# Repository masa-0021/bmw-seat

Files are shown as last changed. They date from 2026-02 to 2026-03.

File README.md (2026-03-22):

# bmw-seat
## Introduction
Since my son is a huge fan of BMW, we created a small project:
* Buy a used passanger seat
* Create a small logic to allow him to enable e. g. seat heater, temperature indicator, and maybe some other equipment
* Screw the seat on a wooden plate and use it as furniture
This Readme shall guide you through the process in case you plan something similar.

### Credits
https://github.com/ironlungx/nvim-pio for providing the platformio plugin for neovim

### Part numbers
Before we rework the seat, let us summarize the different part numbers of the seat and its sub-components:
- Vehicle: BMW F10
- Airbag: 307130710-AD
- Head support: ks726381711
- Seat ECU: BMW 921646801
- Wiring harness: 9 259 205
- Connector: BMW 91676881


## Rework
As a first step, please use a professional service to remove the airbag from the seat. Please note that there might be legal requirements that have to be fulfilled. You should also disconnect the connector from the head support to the ECU below the seat to avoid any kind of emergency action.
In my case, I used a wooden plate (80mmx60mmx18mm) in combination with strips of wood to screw the seat to a wooden basis:
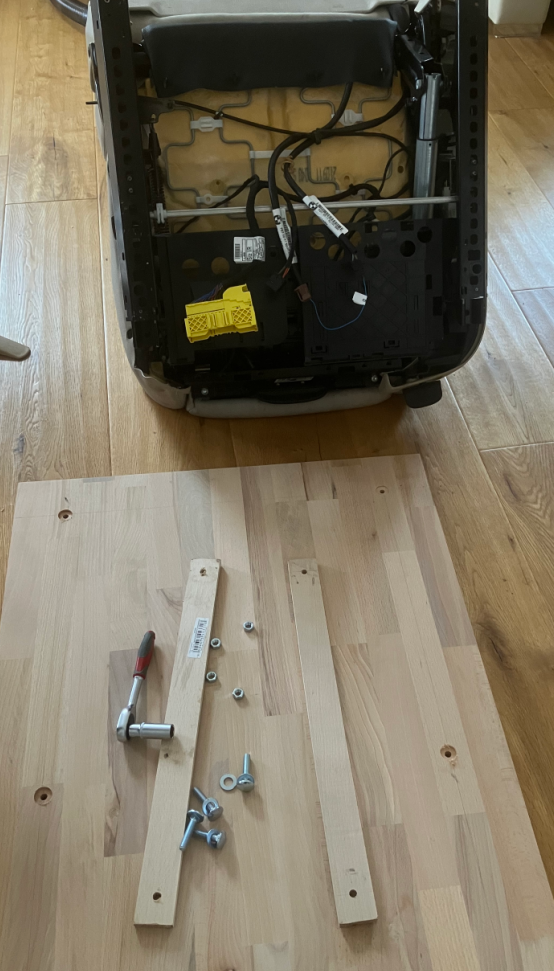
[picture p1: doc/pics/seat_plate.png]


## Electronics
### Seat heater
The seat uses an ECU to control the seat heater. Instead of using the ECU, I disconnected the wiring harness for the back rest and seating surface. Those wiring harnesses have three wires:
- Bround: GND
- Brown/Green: BAT (12V-14V)
- Light grey: Temperature information
According to some measurements, there are strong indications that the temperature pin is connected to GND via a 10kOhm NTC.
The planned implementation will be as follows: By enabling a heater switch, the heater is started. Due to safety concerns, both seat heaters are used in series. A timer of approx. 10mins starts after enabling the heat seater. Once the timer expires, the seat heater is switched off. Additionally, the 10kOhm NTC is monitored and at a temperature beyond 50degC (hysteresis 5degC), the heater is temporarily switched off.
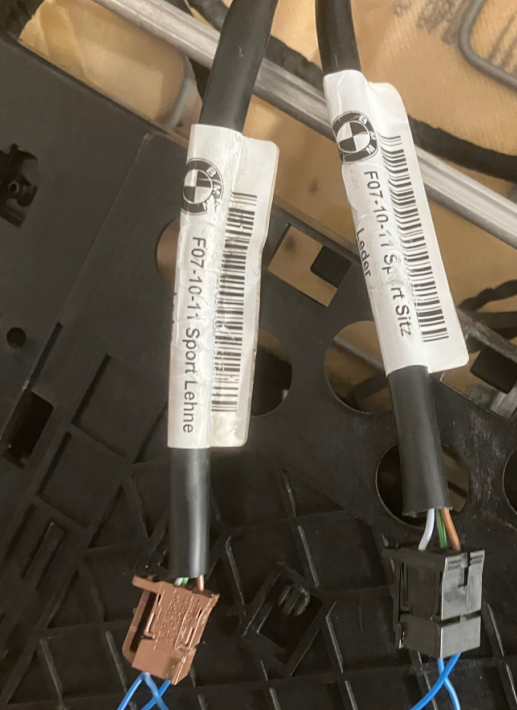
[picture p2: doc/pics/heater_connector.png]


### Fuse
I decided to protect the device with a 5A fuse. Consequently, due to the short wires, 0.5mm2 cable cross section is sufficient.

### Power supply
The system requires UBAT (12V-14V) and a 5V supply for the ATMEGA and the relay. In the first step, I used a passively cooled L7805 (1.5A). Unfortunately, cooling performance was not sufficient. Hence, I decided to use a DC/DC buck converter based on MP1584EN (max. 3A). The output voltage was depending on load and input voltage quite stable: 5.00V +/- 0.05V.

### Seat knobs
Once the main switch is enabled, the seat knobs to change the position of the seat can be used. You only need to connect GND and BAT (12V-14V) to the yellow main connector (brown and red/blue).
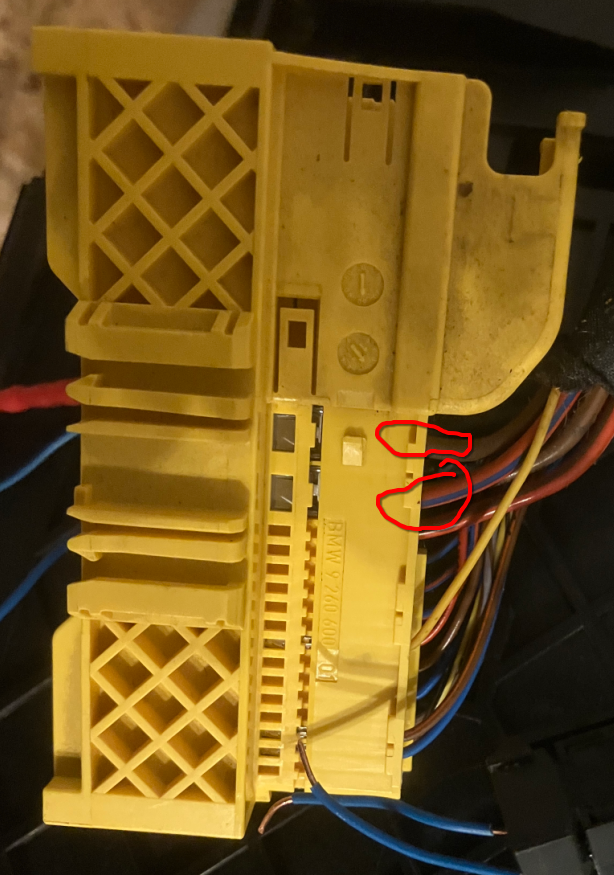
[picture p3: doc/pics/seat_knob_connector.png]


### Switches 
I used two key switches. The first one is a general switch for power supply, both for the seat as well as for the microcontroller ATMEGA328. The purpose of the 2nd switch is the start of the seat heater only.

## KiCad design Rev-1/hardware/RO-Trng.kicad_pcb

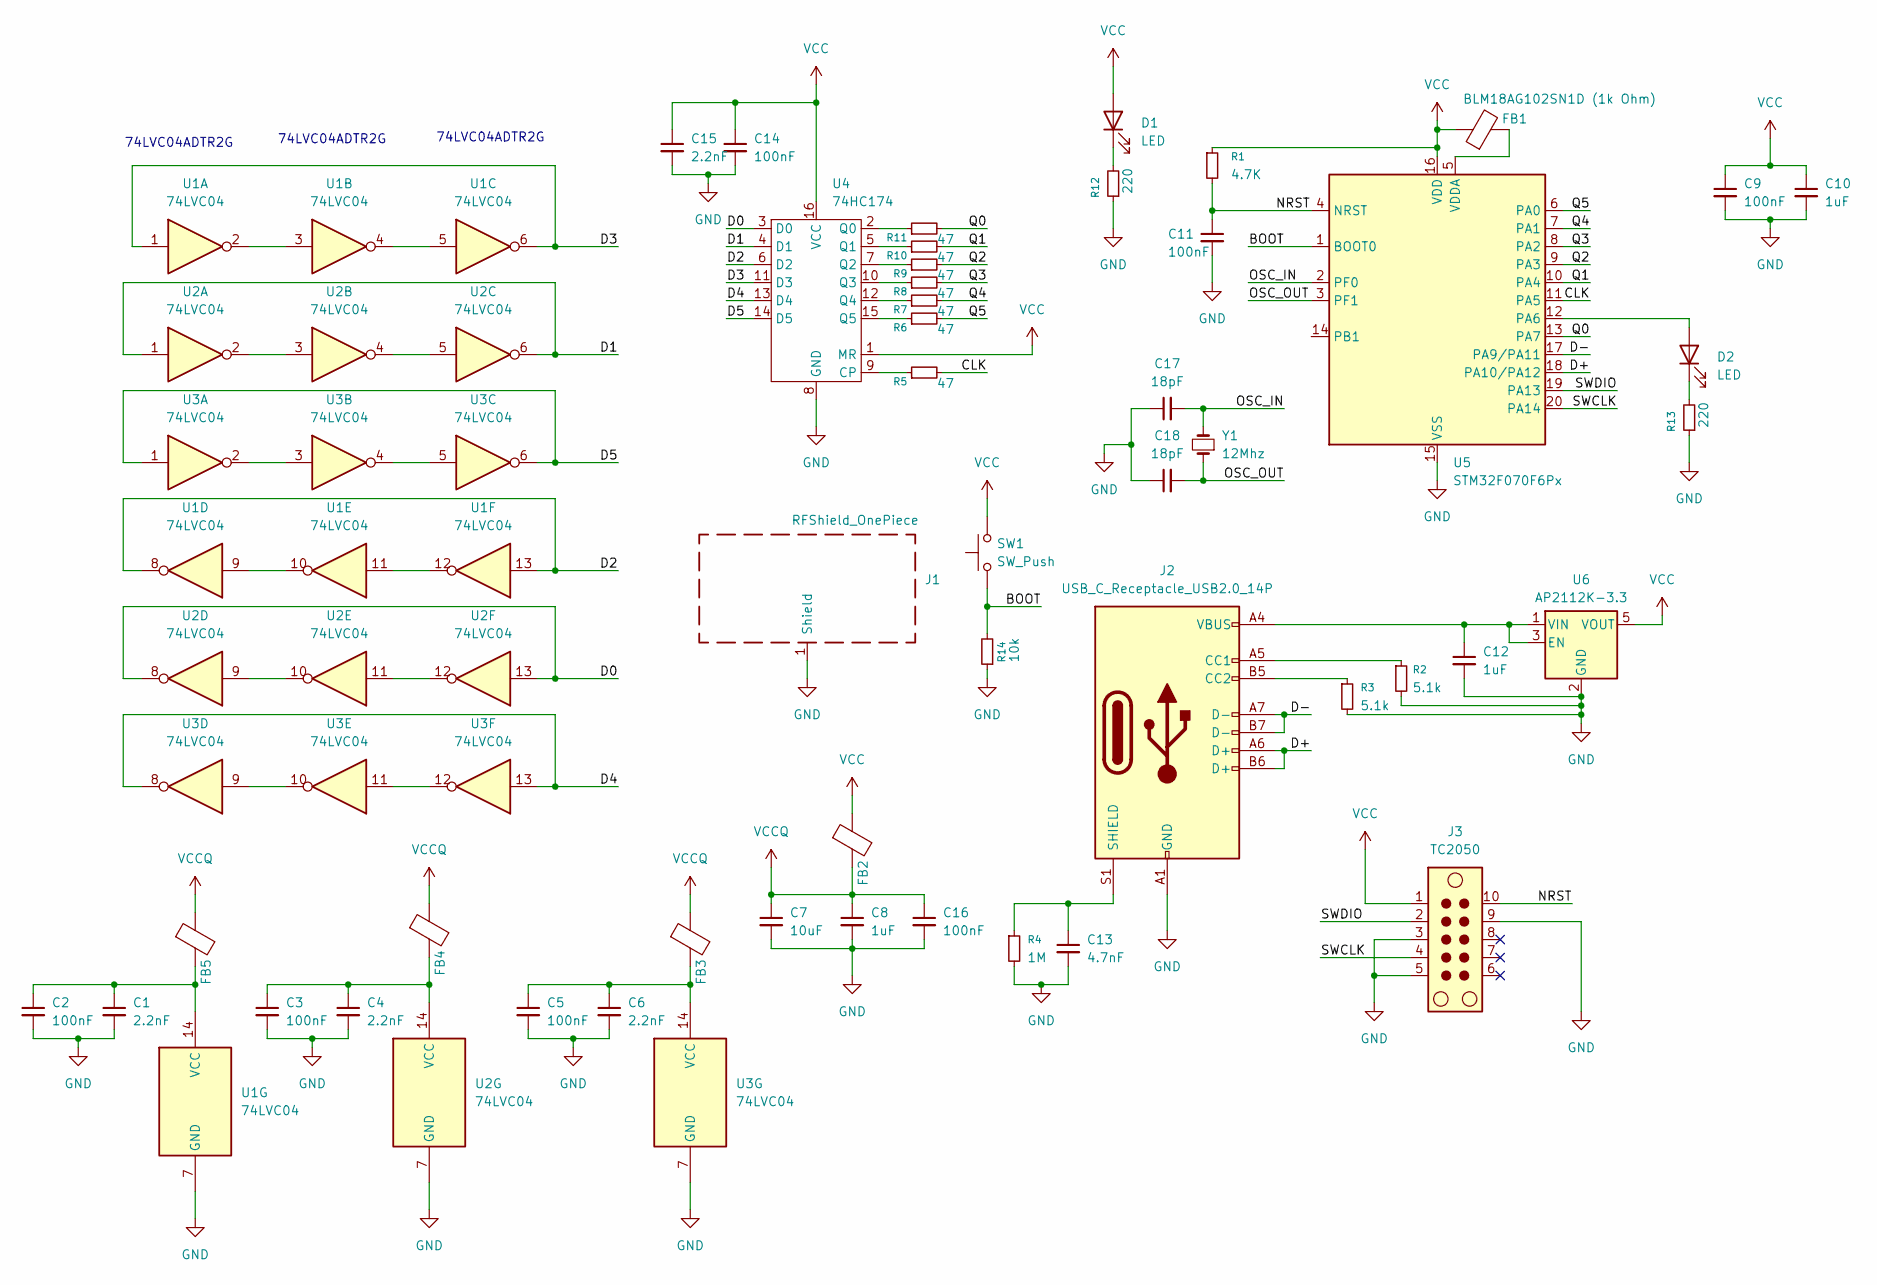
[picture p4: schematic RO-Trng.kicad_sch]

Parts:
C1, C4, C6, C15: 2.2nF; C_0402_1005Metric
C2, C3, C5, C14, C16: 100nF; C_0402_1005Metric
C7: 10uF; C_0805_2012Metric
C8: 1uF; C_0603_1608Metric_Pad1.08x0.95mm_HandSolder
C9, C11: 100nF; C_0603_1608Metric_Pad1.08x0.95mm_HandSolder
C10, C12: 1uF; C_0805_2012Metric
C13: 4.7nF; C_0603_1608Metric_Pad1.08x0.95mm_HandSolder
C17, C18: 18pF; C_0402_1005Metric
D1, D2: LED; LED_0603_1608Metric
FB1, FB2, FB3, FB4, FB5: BLM18AG102SN1D (1k Ohm); R_0603_1608Metric
J1: RFShield_OnePiece; Laird_Technologies_BMI-S-205-F_38.10x25.40mm
J2: USB_C_Receptacle_USB2.0_14P; USB_C_Receptacle_JAE_DX07S016JA1R1500
J3: TC2050; Tag-Connect_TC2050-IDC-NL_2x05_P1.27mm_Vertical
R1: 4.7K; R_0402_1005Metric
R2, R3: 5.1k; R_0402_1005Metric
R4: 1M; R_0402_1005Metric
R5, R6, R7, R8, R9, R10, R11: 47; R_0402_1005Metric
R12, R13: 220; R_0402_1005Metric
R14: 10k; R_0805_2012Metric
SW1: SW_Push; SW_Push_1P1T_XKB_TS-1187A
U1, U2, U3: 74LVC04; TSSOP-14_4.4x5mm_P0.65mm
U4: 74HC174; TSSOP-16_4.4x5mm_P0.65mm
U5: STM32F070F6Px; TSSOP-20_4.4x6.5mm_P0.65mm
U6: AP2112K-3.3; SOT-23-5
Y1: 12Mhz; Crystal_SMD_3225-4Pin_3.2x2.5mm

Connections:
/BOOT: R14.2, SW1.1, U5.1 (BOOT0)
/CLK: R5.2, U5.11 (PA5)
/D0: U2.8, U2.13, U4.3 (D0)
/D1: U2.1, U2.6, U4.4 (D1)
/D2: U1.8, U1.13, U4.6 (D2)
/D3: U1.1, U1.6, U4.11 (D3)
/D4: U3.8, U3.13, U4.13 (D4)
/D5: U3.1, U3.6, U4.14 (D5)
/D+: J2.A6 (D+), J2.B6 (D+), U5.18 (PA10/PA12)
/D-: J2.A7 (D-), J2.B7 (D-), U5.17 (PA9/PA11)
/NRST: C11.1, J3.10, R1.2, U5.4 (NRST)
/OSC_IN: C17.2, U5.2 (PF0), Y1.2
/OSC_OUT: C18.2, U5.3 (PF1), Y1.1
/Q0: R11.2, U5.13 (PA7)
/Q1: R10.2, U5.10 (PA4)
/Q2: R9.2, U5.9 (PA3)
/Q3: R8.2, U5.8 (PA2)
/Q4: R7.2, U5.7 (PA1)
/Q5: R6.2, U5.6 (PA0)
/SWCLK: J3.4, U5.20 (PA14)
/SWDIO: J3.2, U5.19 (PA13)
GND: C1.2, C2.2, C3.2, C4.2, C5.2, C6.2, C7.2, C8.2, C9.2, C10.2, C11.2, C12.2, C13.2, C14.2, C15.2, C16.2, C17.1, C18.1, J1.1 (Shield), J2.A1 (GND), J2.A12 (GND), J2.B1 (GND), J2.B12 (GND), J3.3, J3.5, J3.9, R2.2, R3.2, R4.2, R12.1, R13.1, R14.1, U1.7 (GND), U2.7 (GND), U3.7 (GND), U4.8 (GND), U5.15 (VSS), U6.2 (GND)
unnamed: D1.1 (K), R12.2
unnamed: D2.2 (A), U5.12 (PA6)
unnamed: D2.1 (K), R13.2
unnamed: J2.A5 (CC1), R2.1
unnamed: J2.B5 (CC2), R3.1
unnamed: C13.1, J2.S1 (SHIELD), R4.1
unnamed: U1.2, U1.3
unnamed: U1.4, U1.5
unnamed: U1.9, U1.10
unnamed: U1.11, U1.12
unnamed: C1.1, C2.1, FB5.2, U1.14 (VCC)
unnamed: U2.2, U2.3
unnamed: U2.4, U2.5
unnamed: U2.9, U2.10
unnamed: U2.11, U2.12
unnamed: C3.1, C4.1, FB4.2, U2.14 (VCC)
unnamed: U3.2, U3.3
unnamed: U3.4, U3.5
unnamed: U3.9, U3.10
unnamed: U3.11, U3.12
unnamed: C5.1, C6.1, FB3.2, U3.14 (VCC)
unnamed: R5.1, U4.9 (CP)
unnamed: R11.1, U4.2 (Q0)
unnamed: R10.1, U4.5 (Q1)
unnamed: R9.1, U4.7 (Q2)
unnamed: R8.1, U4.10 (Q3)
unnamed: R7.1, U4.12 (Q4)
unnamed: R6.1, U4.15 (Q5)
unnamed: FB1.2, U5.5 (VDDA)
unnamed: C12.1, J2.A4 (VBUS), J2.A9 (VBUS), J2.B4 (VBUS), J2.B9 (VBUS), U6.1 (VIN), U6.3 (EN)
VCC: C9.1, C10.1, C14.1, C15.1, D1.2 (A), FB1.1, FB2.1, J3.1, R1.1, SW1.2, U4.1 (MR), U4.16 (VCC), U5.16 (VDD), U6.5 (VOUT)
VCCQ: C7.1, C8.1, C16.1, FB2.2, FB3.1, FB4.1, FB5.1

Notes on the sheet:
74LVC04ADTR2G

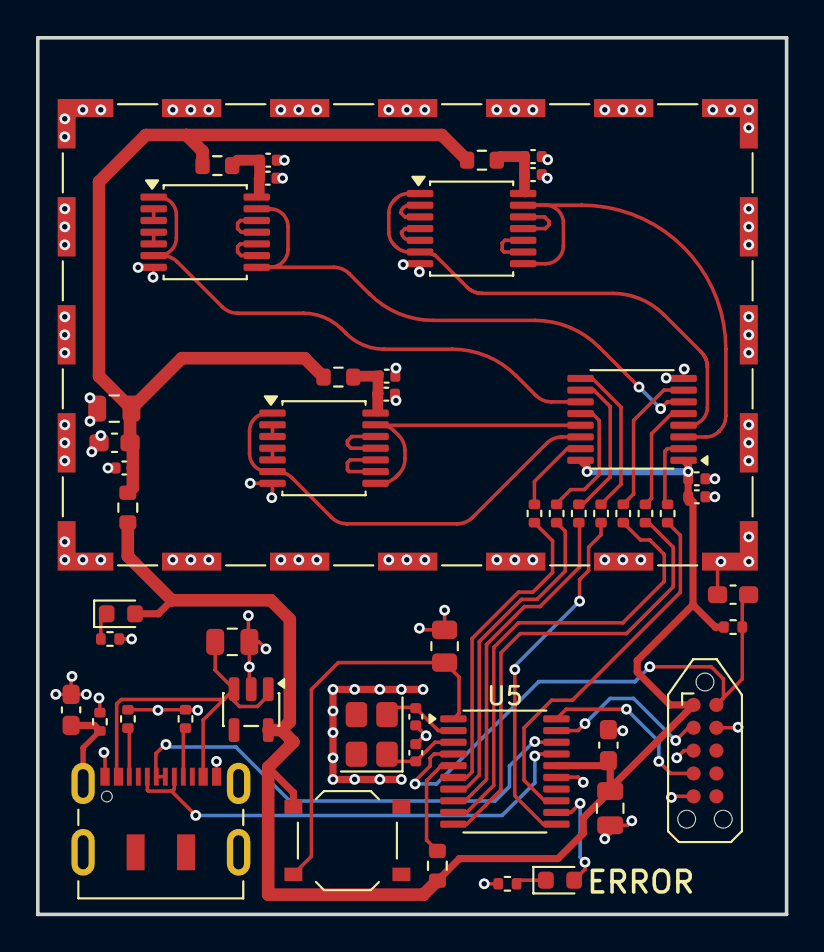
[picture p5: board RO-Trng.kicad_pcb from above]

Board: 2 copper layers, 41.6 x 48.7 mm, 50 parts (0 on the bottom side), 54 nets.

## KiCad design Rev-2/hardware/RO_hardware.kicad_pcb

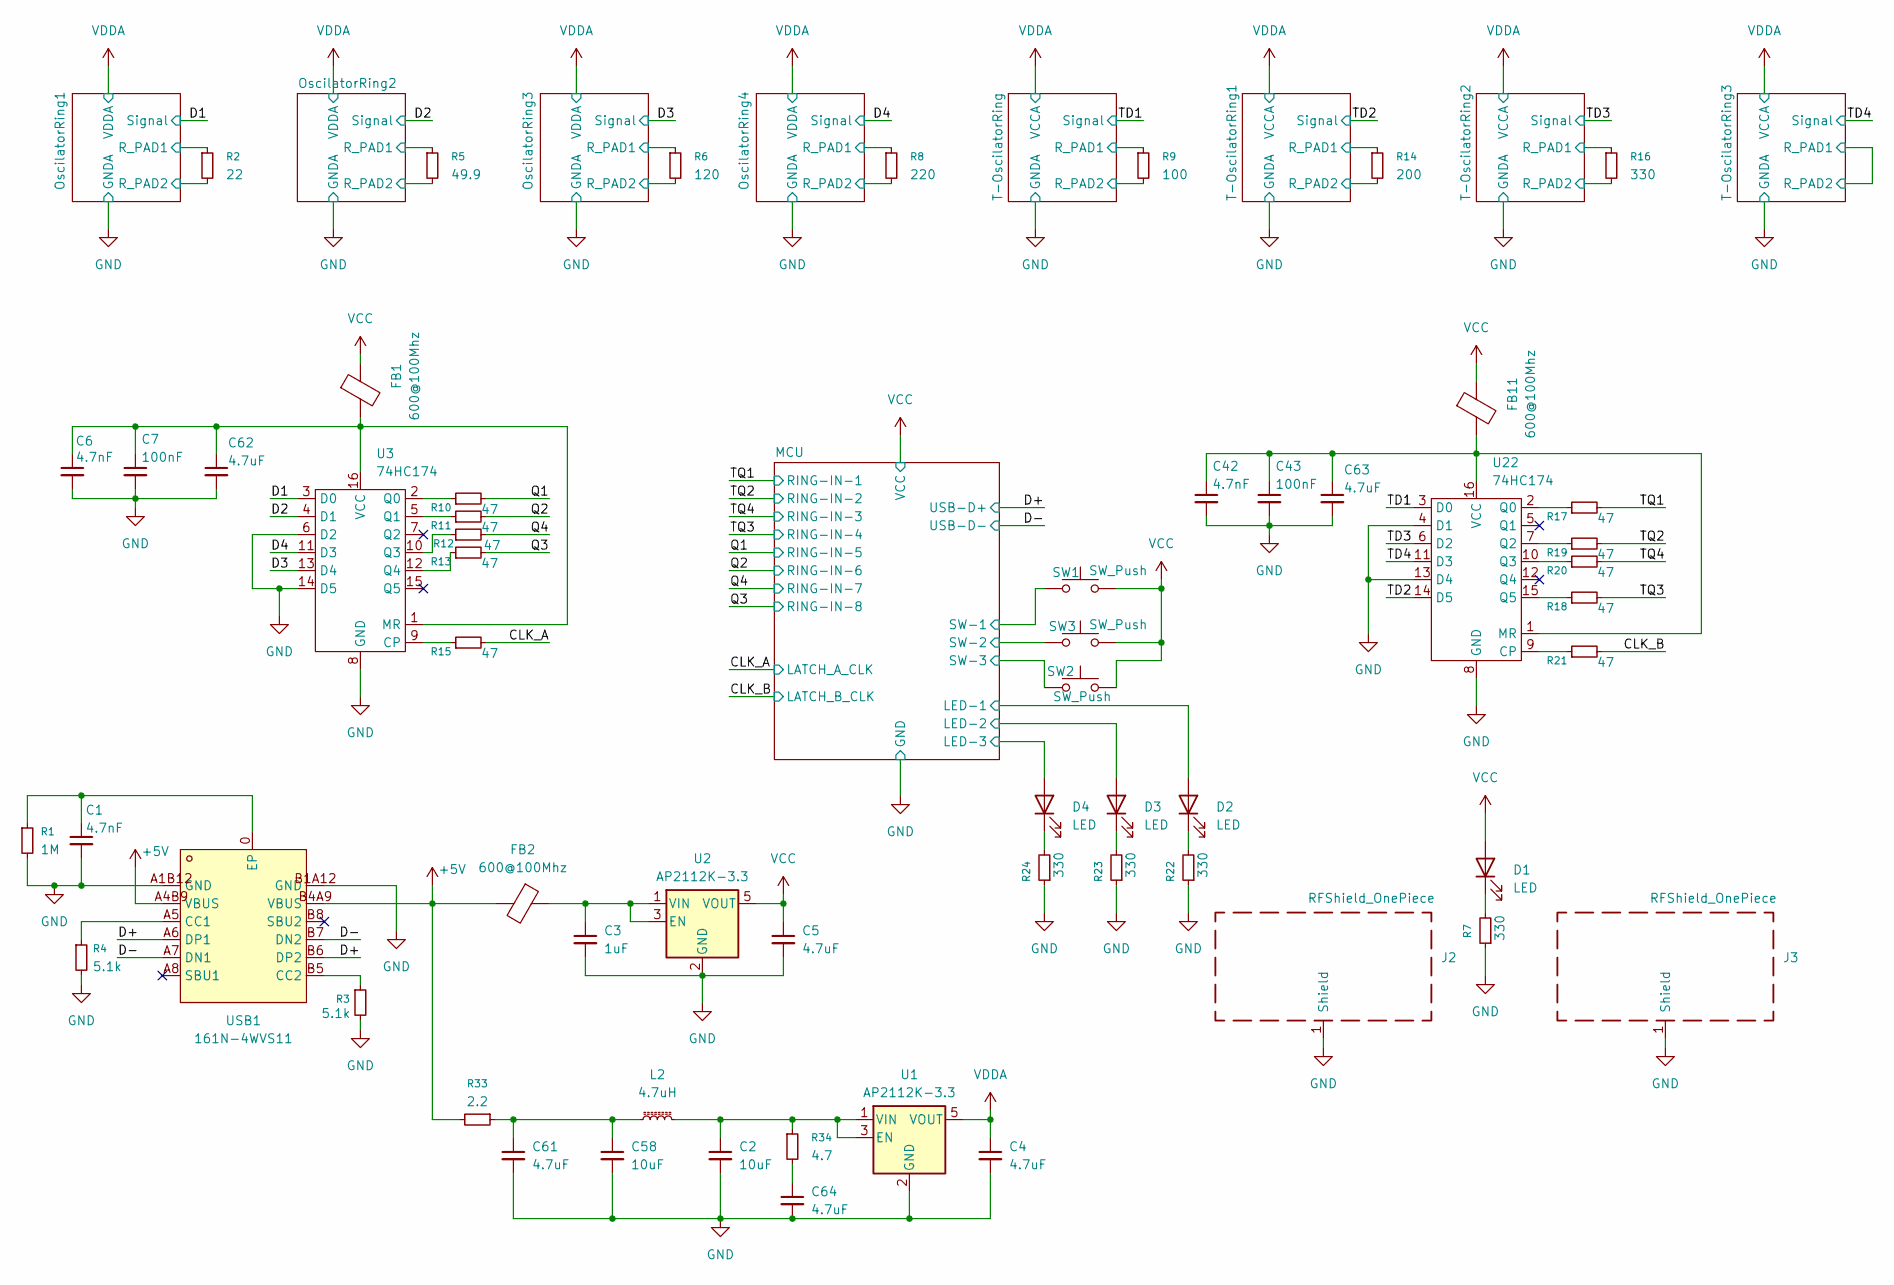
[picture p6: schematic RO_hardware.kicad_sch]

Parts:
C1: 4.7nF; C_0805_2012Metric
C2, C58: 10uF; C_1206_3216Metric
C3: 1uF; C_1206_3216Metric
C4, C5, C61, C62, C63, C64: 4.7uF; C_1206_3216Metric
C6, C42: 4.7nF; C_0402_1005Metric
C7, C43: 100nF; C_0402_1005Metric
D1, D2, D3, D4: LED; D_0805_2012Metric
FB1, FB2, FB11: 600@100Mhz; R_0603_1608Metric
J2, J3: RFShield_OnePiece; Laird_Technologies_BMI-S-205-F_38.10x25.40mm
L2: 4.7uH; L_1008_2520Metric
R1: 1M; R_0805_2012Metric
R2: 22; R_0402_1005Metric
R3, R4: 5.1k; R_0805_2012Metric
R5: 49.9; R_0402_1005Metric
R6: 120; R_0402_1005Metric
R7, R22, R23, R24: 330; R_0805_2012Metric
R8: 220; R_0402_1005Metric
R9: 100; R_0402_1005Metric
R10, R11, R12, R13, R15, R17, R18, R19, R20, R21: 47; R_0402_1005Metric
R14: 200; R_0402_1005Metric
R16: 330; R_0402_1005Metric
R33: 2.2; R_0805_2012Metric
R34: 4.7; R_0603_1608Metric
SW1, SW2, SW3: SW_Push; XKBConnection-TS_1187A_B_AB
U1, U2: AP2112K-3.3; SOT-23-5
U3, U22: 74HC174; TSSOP-16_4.4x5mm_P0.65mm
USB1: 161N-4WVS11; USB-C-SMD_HANELECTRICITY_161N-4XVS11; MPN 161N-4WVS11; LCSC Part C5440753

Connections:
+5V: FB2.2, R33.2, USB1.A4B9 (VBUS), USB1.B4A9 (VBUS)
/CLK_A: R15.2; also elsewhere on the board
/CLK_B: R21.2; also elsewhere on the board
/D1: R2.1, U3.3 (D0); also elsewhere on the board
/D2: R5.1, U3.4 (D1); also elsewhere on the board
/D3: R6.1, U3.13 (D4); also elsewhere on the board
/D4: R8.1, U3.11 (D3); also elsewhere on the board
/D+: USB1.A6 (DP1), USB1.B6 (DP2); also elsewhere on the board
/D-: USB1.A7 (DN1), USB1.B7 (DN2); also elsewhere on the board
/MCU/LED-1: D2.2 (A); also elsewhere on the board
/MCU/LED-2: D3.2 (A); also elsewhere on the board
/MCU/LED-3: D4.2 (A); also elsewhere on the board
/MCU/SW-1: SW1.1; also elsewhere on the board
/MCU/SW-2: SW3.1; also elsewhere on the board
/MCU/SW-3: SW2.1; also elsewhere on the board
/OscilatorRing1/R_PAD2: R2.2; also elsewhere on the board
/OscilatorRing2/R_PAD2: R5.2; also elsewhere on the board
/OscilatorRing3/R_PAD2: R6.2; also elsewhere on the board
/OscilatorRing4/R_PAD2: R8.2; also elsewhere on the board
/Q1: R10.2; also elsewhere on the board
/Q2: R11.2; also elsewhere on the board
/Q3: R13.2; also elsewhere on the board
/Q4: R12.2; also elsewhere on the board
/T-OscilatorRing1/R_PAD2: R14.2; also elsewhere on the board
/T-OscilatorRing2/R_PAD2: R16.2; also elsewhere on the board
/T-OscilatorRing/R_PAD2: R9.2; also elsewhere on the board
/TD1: R9.1, U22.3 (D0); also elsewhere on the board
/TD2: R14.1, U22.14 (D5); also elsewhere on the board
/TD3: R16.1, U22.6 (D2); also elsewhere on the board
/TD4: U22.11 (D3); also elsewhere on the board
/TQ1: R17.2; also elsewhere on the board
/TQ2: R19.2; also elsewhere on the board
/TQ3: R18.2; also elsewhere on the board
/TQ4: R20.2; also elsewhere on the board
GND: C1.2, C2.2, C3.2, C4.2, C5.2, C6.2, C7.2, C42.2, C43.2, C58.2, C61.2, C62.2, C63.2, C64.2, J2.1 (Shield), J3.1 (Shield), R1.2, R3.2, R4.2, R7.1, R22.1, R23.1, R24.1, U1.2 (GND), U2.2 (GND), U3.6 (D2), U3.8 (GND), U3.14 (D5), U22.4 (D1), U22.8 (GND), U22.13 (D4), USB1.A1B12 (GND), USB1.B1A12 (GND); also elsewhere on the board
unnamed: C58.1, C61.1, L2.1, R33.1
unnamed: C64.1, R34.2
unnamed: D1.1 (K), R7.2
unnamed: D2.1 (K), R22.2
unnamed: D3.1 (K), R23.2
unnamed: D4.1 (K), R24.2
unnamed: C2.1, L2.2, R34.1, U1.1 (VIN), U1.3 (EN)
unnamed: C3.1, FB2.1, U2.1 (VIN), U2.3 (EN)
unnamed: R15.1, U3.9 (CP)
unnamed: C6.1, C7.1, C62.1, FB1.2, U3.1 (MR), U3.16 (VCC)
unnamed: R10.1, U3.2 (Q0)
unnamed: R11.1, U3.5 (Q1)
unnamed: R12.1, U3.10 (Q3)
unnamed: R13.1, U3.12 (Q4)
unnamed: R21.1, U22.9 (CP)
unnamed: C42.1, C43.1, C63.1, FB11.2, U22.1 (MR), U22.16 (VCC)
unnamed: R17.1, U22.2 (Q0)
unnamed: R19.1, U22.7 (Q2)
unnamed: R20.1, U22.10 (Q3)
unnamed: R18.1, U22.15 (Q5)
unnamed: R4.1, USB1.A5 (CC1)
unnamed: R3.1, USB1.B5 (CC2)
unnamed: C1.1, R1.1, USB1.0 (EP)
VCC: C5.1, D1.2 (A), FB1.1, FB11.1, SW1.2, SW2.2, SW3.2, U2.5 (VOUT); also elsewhere on the board
VDDA: C4.1, U1.5 (VOUT); also elsewhere on the board

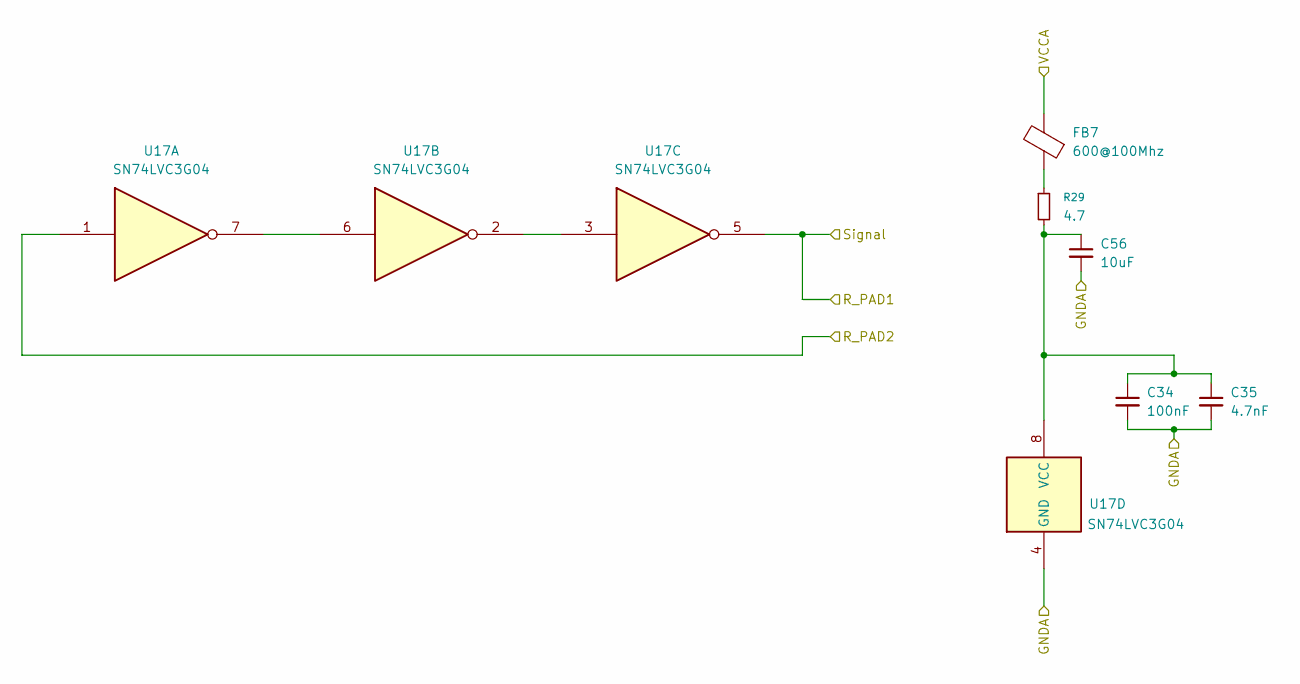
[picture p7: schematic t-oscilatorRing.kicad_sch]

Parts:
C34: 100nF; C_0402_1005Metric
C35: 4.7nF; C_0402_1005Metric
C56: 10uF; C_0805_2012Metric
FB7: 600@100Mhz; R_0603_1608Metric
R29: 4.7; R_0603_1608Metric
U17: SN74LVC3G04; MSOP-8_3x3mm_P0.65mm

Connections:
/T-OscilatorRing/R_PAD2: U17.1; also elsewhere on the board
/TD1: U17.5; also elsewhere on the board
GND: C34.2, C35.2, C56.2, U17.4 (GND); also elsewhere on the board
unnamed: FB7.1, R29.1
unnamed: U17.2, U17.3
unnamed: U17.6, U17.7
unnamed: C34.1, C35.1, C56.1, R29.2, U17.8 (VCC)
VDDA: FB7.2; also elsewhere on the board

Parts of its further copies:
C36, C38, C40: 100nF; C_0402_1005Metric
C37, C39, C41: 4.7nF; C_0402_1005Metric
C57, C59, C60: 10uF; C_0805_2012Metric
FB8, FB9, FB10: 600@100Mhz; R_0603_1608Metric
R30, R31, R32: 4.7; R_0603_1608Metric
U18, U19, U20: SN74LVC3G04; MSOP-8_3x3mm_P0.65mm

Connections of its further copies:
/T-OscilatorRing1/R_PAD2: U18.1; also elsewhere on the board
/T-OscilatorRing2/R_PAD2: U19.1; also elsewhere on the board
/TD2: U18.5; also elsewhere on the board
/TD3: U19.5; also elsewhere on the board
/TD4: U20.1, U20.5; also elsewhere on the board
GND: C36.2, C37.2, C38.2, C39.2, C40.2, C41.2, C57.2, C59.2, C60.2, U18.4 (GND), U19.4 (GND), U20.4 (GND); also elsewhere on the board
unnamed: FB8.1, R30.1
unnamed: FB9.1, R31.1
unnamed: FB10.1, R32.1
unnamed: U18.2, U18.3
unnamed: U18.6, U18.7
unnamed: C36.1, C37.1, C57.1, R30.2, U18.8 (VCC)
unnamed: U19.2, U19.3
unnamed: U19.6, U19.7
unnamed: C38.1, C39.1, C59.1, R31.2, U19.8 (VCC)
unnamed: U20.2, U20.3
unnamed: U20.6, U20.7
unnamed: C40.1, C41.1, C60.1, R32.2, U20.8 (VCC)
VDDA: FB8.2, FB9.2, FB10.2; also elsewhere on the board

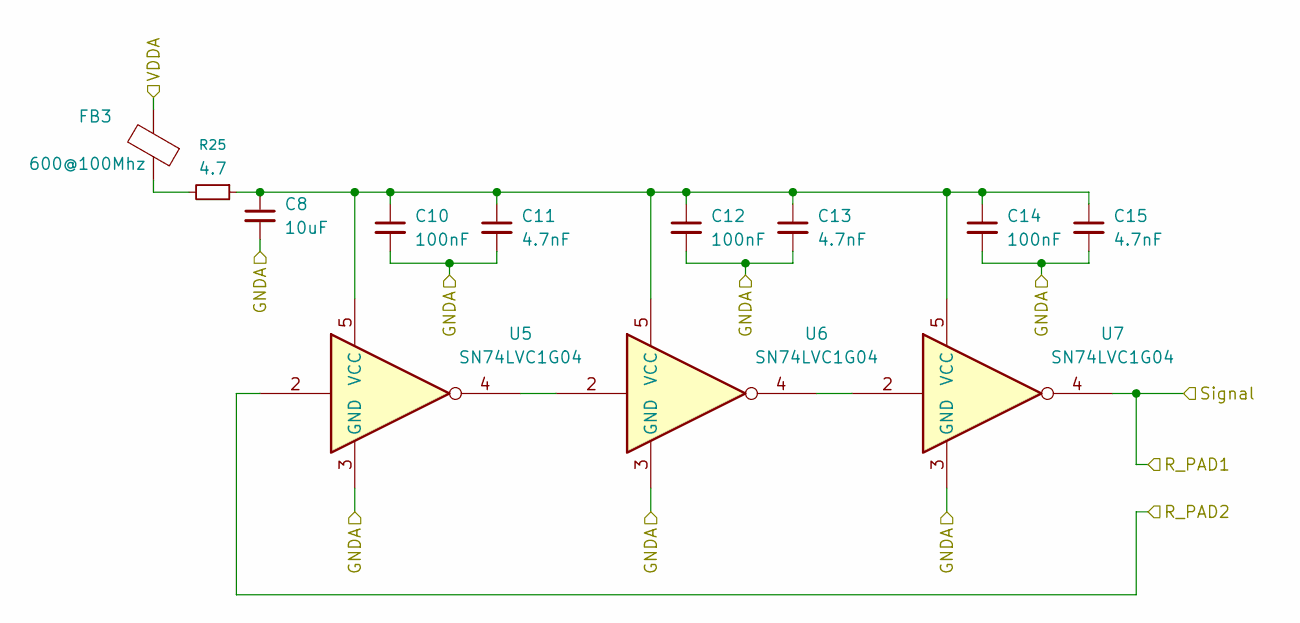
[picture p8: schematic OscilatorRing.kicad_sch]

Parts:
C8: 10uF; C_0805_2012Metric
C10, C12, C14: 100nF; C_0402_1005Metric
C11, C13, C15: 4.7nF; C_0402_1005Metric
FB3: 600@100Mhz; R_0603_1608Metric
R25: 4.7; R_0603_1608Metric
U5, U6, U7: SN74LVC1G04; SOT-353_SC-70-5

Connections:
/D1: U7.4; also elsewhere on the board
/OscilatorRing1/R_PAD2: U5.2; also elsewhere on the board
GND: C8.2, C10.2, C11.2, C12.2, C13.2, C14.2, C15.2, U5.3 (GND), U6.3 (GND), U7.3 (GND); also elsewhere on the board
unnamed: FB3.1, R25.2
unnamed: U5.4, U6.2
unnamed: C8.1, C10.1, C11.1, C12.1, C13.1, C14.1, C15.1, R25.1, U5.5 (VCC), U6.5 (VCC), U7.5 (VCC)
unnamed: U6.4, U7.2
VDDA: FB3.2; also elsewhere on the board

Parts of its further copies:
C9, C44, C45: 10uF; C_0805_2012Metric
C16, C18, C20, C22, C24, C26, C28, C30, C32: 100nF; C_0402_1005Metric
C17, C19, C21, C23, C25, C27, C29, C31, C33: 4.7nF; C_0402_1005Metric
FB4, FB5, FB6: 600@100Mhz; R_0603_1608Metric
R26, R27, R28: 4.7; R_0603_1608Metric
U8, U9, U10, U11, U12, U13, U14, U15, U16: SN74LVC1G04; SOT-353_SC-70-5

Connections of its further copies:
/D2: U10.4; also elsewhere on the board
/D3: U13.4; also elsewhere on the board
/D4: U16.4; also elsewhere on the board
/OscilatorRing2/R_PAD2: U8.2; also elsewhere on the board
/OscilatorRing3/R_PAD2: U11.2; also elsewhere on the board
/OscilatorRing4/R_PAD2: U14.2; also elsewhere on the board
GND: C9.2, C16.2, C17.2, C18.2, C19.2, C20.2, C21.2, C22.2, C23.2, C24.2, C25.2, C26.2, C27.2, C28.2, C29.2, C30.2, C31.2, C32.2, C33.2, C44.2, C45.2, U8.3 (GND), U9.3 (GND), U10.3 (GND), U11.3 (GND), U12.3 (GND), U13.3 (GND), U14.3 (GND), U15.3 (GND), U16.3 (GND); also elsewhere on the board
unnamed: FB4.1, R26.2
unnamed: FB5.1, R27.2
unnamed: FB6.1, R28.2
unnamed: U8.4, U9.2
unnamed: U9.4, U10.2
unnamed: C9.1, C16.1, C17.1, C18.1, C19.1, C20.1, C21.1, R26.1, U8.5 (VCC), U9.5 (VCC), U10.5 (VCC)
unnamed: U11.4, U12.2
unnamed: C22.1, C23.1, C24.1, C25.1, C26.1, C27.1, C44.1, R27.1, U11.5 (VCC), U12.5 (VCC), U13.5 (VCC)
unnamed: U12.4, U13.2
unnamed: U14.4, U15.2
unnamed: C28.1, C29.1, C30.1, C31.1, C32.1, C33.1, C45.1, R28.1, U14.5 (VCC), U15.5 (VCC), U16.5 (VCC)
unnamed: U15.4, U16.2
VDDA: FB4.2, FB5.2, FB6.2; also elsewhere on the board

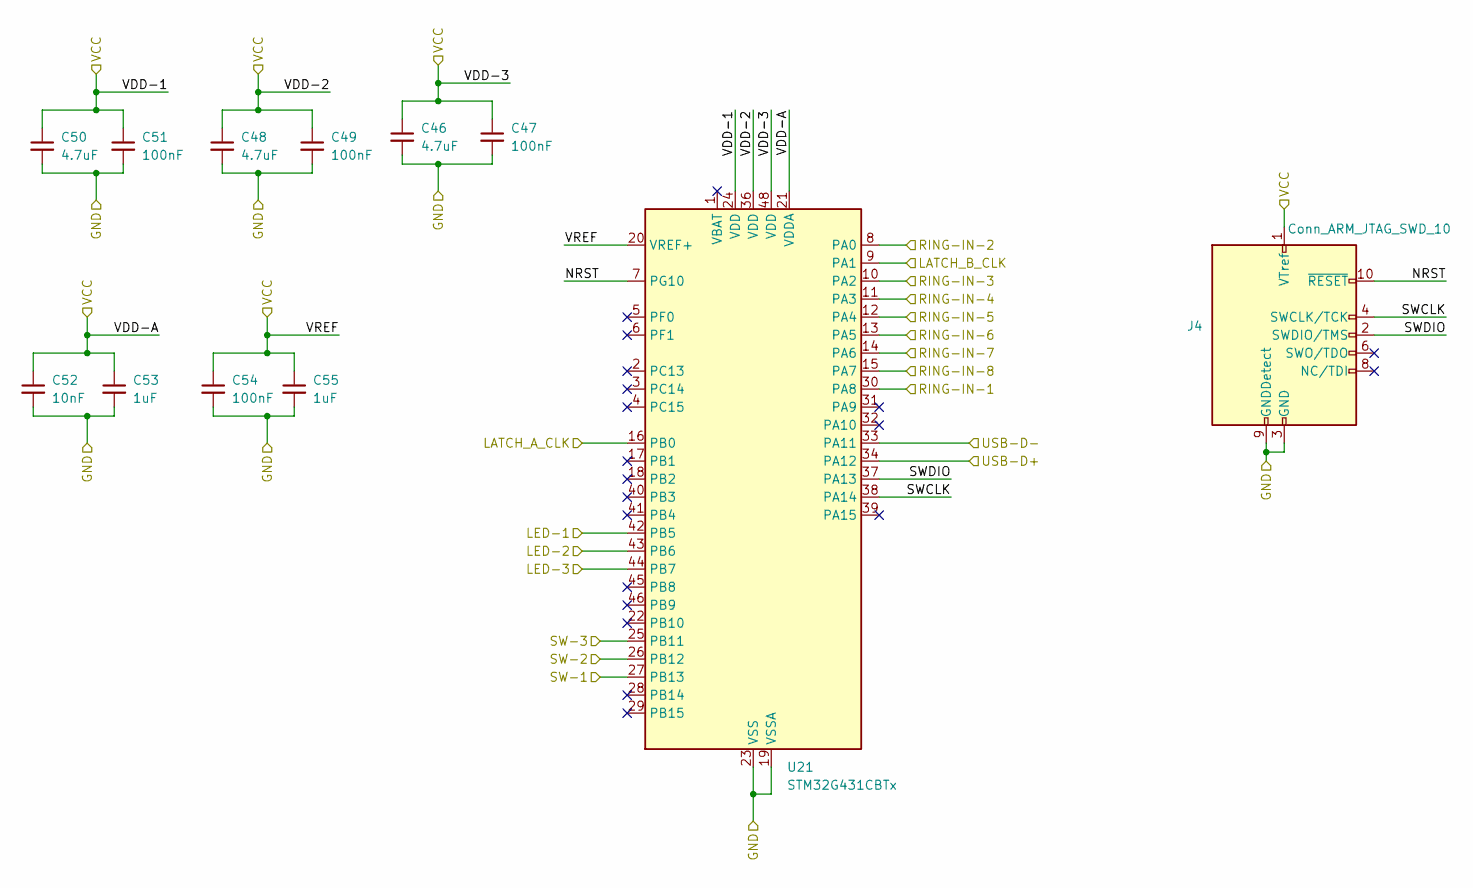
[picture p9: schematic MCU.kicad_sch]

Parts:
C46, C48, C50: 4.7uF; C_1206_3216Metric
C47, C49, C51, C54: 100nF; C_1206_3216Metric
C52: 10nF; C_1206_3216Metric
C53, C55: 1uF; C_1206_3216Metric
J4: Conn_ARM_JTAG_SWD_10; Tag-Connect_TC2050-IDC-NL_2x05_P1.27mm_Vertical
U21: STM32G431CBTx; LQFP-48_7x7mm_P0.5mm

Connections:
/CLK_A: U21.16 (PB0); also elsewhere on the board
/CLK_B: U21.9 (PA1); also elsewhere on the board
/D+: U21.34 (PA12); also elsewhere on the board
/D-: U21.33 (PA11); also elsewhere on the board
/MCU/LED-1: U21.42 (PB5); also elsewhere on the board
/MCU/LED-2: U21.43 (PB6); also elsewhere on the board
/MCU/LED-3: U21.44 (PB7); also elsewhere on the board
/MCU/NRST: J4.10 (~RESET), U21.7 (PG10)
/MCU/SW-1: U21.27 (PB13); also elsewhere on the board
/MCU/SW-2: U21.26 (PB12); also elsewhere on the board
/MCU/SW-3: U21.25 (PB11); also elsewhere on the board
/MCU/SWCLK: J4.4 (SWCLK/TCK), U21.38 (PA14)
/MCU/SWDIO: J4.2 (SWDIO/TMS), U21.37 (PA13)
/Q1: U21.12 (PA4); also elsewhere on the board
/Q2: U21.13 (PA5); also elsewhere on the board
/Q3: U21.15 (PA7); also elsewhere on the board
/Q4: U21.14 (PA6); also elsewhere on the board
/TQ1: U21.30 (PA8); also elsewhere on the board
/TQ2: U21.8 (PA0); also elsewhere on the board
/TQ3: U21.11 (PA3); also elsewhere on the board
/TQ4: U21.10 (PA2); also elsewhere on the board
GND: C46.2, C47.2, C48.2, C49.2, C50.2, C51.2, C52.2, C53.2, C54.2, C55.2, J4.3 (GND), J4.5 (GND), J4.9 (GNDDetect), U21.19 (VSSA), U21.23 (VSS), U21.35 (VSS), U21.47 (VSS); also elsewhere on the board
VCC: C46.1, C47.1, C48.1, C49.1, C50.1, C51.1, C52.1, C53.1, C54.1, C55.1, J4.1 (VTref), U21.20 (VREF+), U21.21 (VDDA), U21.24 (VDD), U21.36 (VDD), U21.48 (VDD); also elsewhere on the board

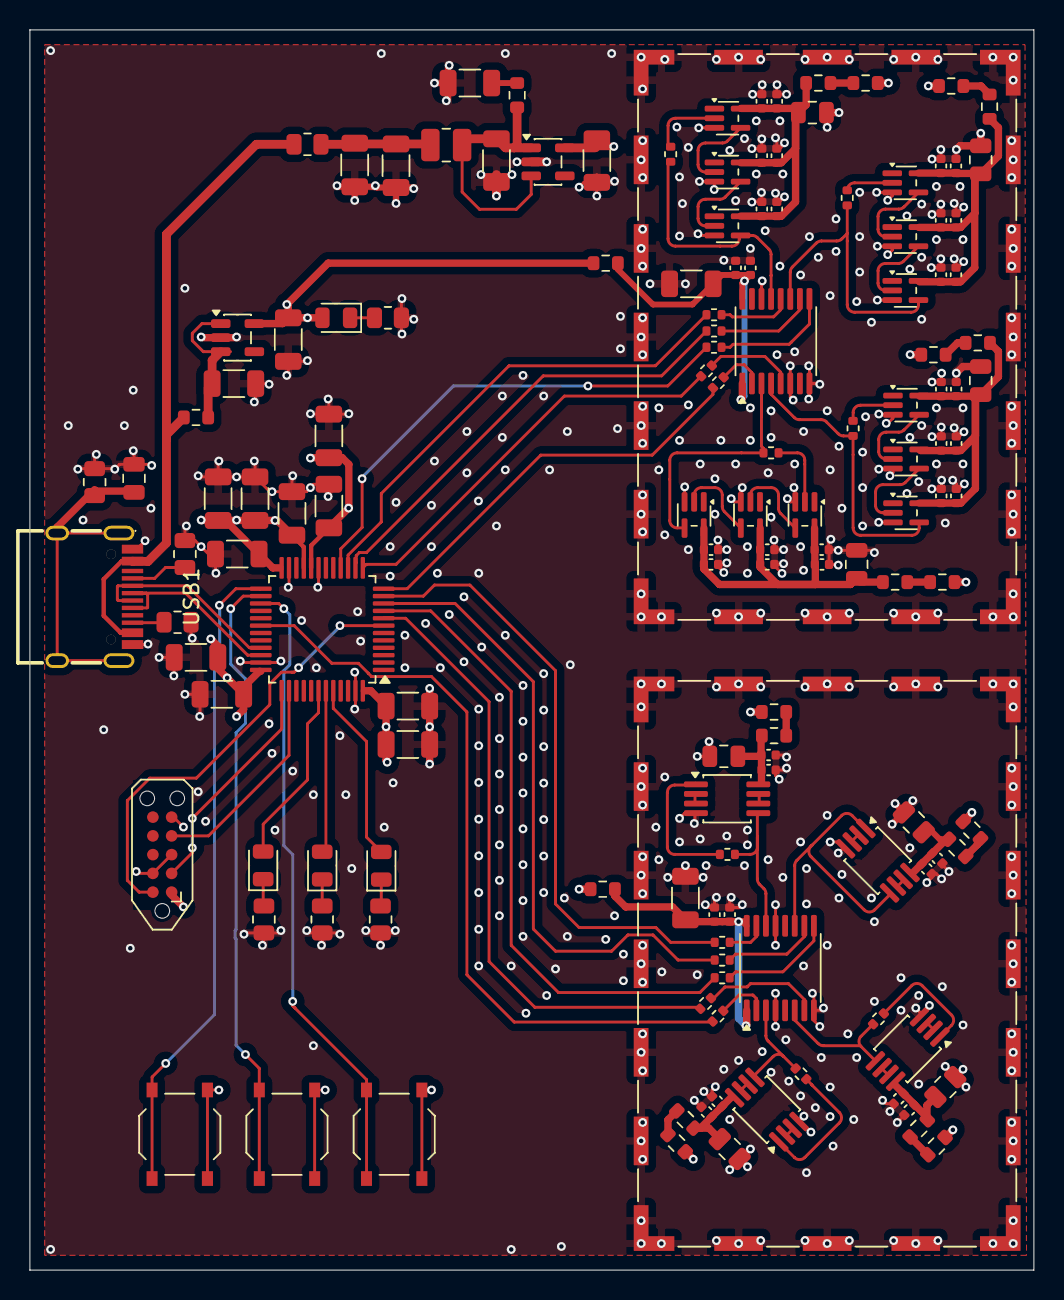
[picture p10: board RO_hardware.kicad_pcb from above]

Board: 4 copper layers, 68.0 x 84.0 mm, 142 parts (0 on the bottom side), 95 nets.

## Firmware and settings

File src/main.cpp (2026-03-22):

#include <Arduino.h>
#include <Wire.h>
#include <LiquidCrystal_I2C.h>

// If you comment this line, the DPRINT & DPRINTLN lines are
#define DEBUG

#ifdef DEBUG // Macros are usually in all capital letters.
#define DPRINT(...) Serial.print(__VA_ARGS__) // DPRINT is a macro, debug print
#define DPRINTLN(...)                                                          \
    Serial.println(__VA_ARGS__) // DPRINTLN is a macro, debug print with new line
#else
#define DPRINT(...)   // now defines a blank line
#define DPRINTLN(...) // now defines a blank line
#endif

//#define SIMULATION
#ifdef SIMULATION
#define OVERWRITE(a,b) a = b;
#else
#define OVERWRITE(...)
#endif

/* Display settings */
const uint8_t Disp_I2C_Addr = 0x27;
const uint8_t Disp_Cols = 20;
const uint8_t Disp_Rows = 4;

/* Initialize the display */
LiquidCrystal_I2C lcd = LiquidCrystal_I2C(Disp_I2C_Addr, Disp_Cols, Disp_Rows);

/* ADC connected to connector 2
 * Reference voltage divider:
 * Two 10kOhm voltage divider
 * ADC reference: 5V
 * ADC = 1023 corresponds to 5V
 * Due to symmetric voltage divider, double the value for reference voltage */
const uint8_t AnalogPinRef = A1;

float readRefVoltage() {
    int val = analogRead(AnalogPinRef);
    return( (float)(2 * val * 5)/1023.0f);
}

const unsigned int arrSize = 13;
const int TempArr[arrSize] = {60, 55, 50, 45, 40, 35, 30, 25, 20, 15, 10, 5, 0};
const int ResArr[arrSize] = {2996, 3513, 4137, 4891, 5809, 6929, 8304, 10000, 12100, 14720, 18000, 22130, 27350};
/* Getter for 10kOhm NTC
 * 27.35 kOhm -> 0degC
 * 22.13 kOhm -> 5degC
 * 18.00 kOhm -> 10degC
 * 14.72 kOhm -> 15degC
 * 12.10 kOhm -> 20degC
 * 10.00 kOhm -> 25degC
 * 8.304 kOhm -> 30degC
 * 6.929 kOhm -> 35degC
 * 5.809 kOhm -> 40degC
 * 4.891 kOhm -> 45degC
 * 4.137 kOhm -> 50degC
 * 3.513 kOhm -> 55degC
 * 2.996 kOhm -> 60degC */


int convertTemp(int resNTC){
    DPRINT("convertTemp: resNTC is: ");
    DPRINT(resNTC);
    DPRINT("\n");

    if( resNTC <= ResArr[0])
        return TempArr[0];

    if( resNTC >= ResArr[12])
        return TempArr[12];
    
    for( int i = 0; i < 12; ++i ) {
        if (resNTC == ResArr[i])
            return TempArr[i];

        if( resNTC > ResArr[i] && resNTC < ResArr[i+1]) {
            float d = ( (float) (resNTC - ResArr[i])) / ((float) (ResArr[i+1]-ResArr[i]));
            return ( TempArr[i] + (int) (d*(TempArr[i+1]-TempArr[i])) );
        }
    }

    return(TempArr[12]);
}


/* Temperature seat 1
 * 10 kOhm NTC + Voltage Divider with 10kOhm, supplied by reference voltage
 * ADC reference: 5V
 * ADC = 1023 corresponds to 5V ADC
 * RNTC = 10 kOhm x (Uref/Uadc - 1)
 * Uadc = ADC/1023 x 5V
 * RNTC = 10.000 Ohm * (Uref*1023/ADC x 5V - 1)
 */
const int analogPinSeat1 = A0;

int readNTCSeat1(float uref) {
    int val = analogRead(analogPinSeat1);
    long tmp_res = (long) (10000.0f*(uref/val * 1023.0f / 5.0f - 1.0f));
    int res;
    if (tmp_res < -32768) {
        res = -32768;
    } else if (tmp_res > 32767) {
        res = 32767;
    } else {
        res = (int) tmp_res;
    }

    DPRINT("readNTCSeat1: val & uref & resNTC: ");
    DPRINT(val);
    DPRINT(" ");
    DPRINT(uref);
    DPRINT(" ");
    DPRINT(res);
    DPRINT("\n");

    return( res );
}

/* Temperature seat 2
 * 10 kOhm NTC + Voltage Divider with 10kOhm, supplied by reference voltage
 * ADC reference: 5V
 * ADC = 1023 corresponds to 5V ADC
 * RNTC = 10 kOhm x (Uref/Uadc - 1)
 * Uadc = ADC/1023 x 5V
 * RNTC = 10.000 Ohm * (Uref/(ADC/1023 x 5V) - 1)
 */
const int analogPinSeat2 = A3;

int readNTCSeat2(float uref) {
    int val = analogRead(analogPinSeat2);
    long tmp_res = (long) (10000.0f*(uref/val * 1023.0f / 5.0f - 1.0f));
    int res;
    if (tmp_res < -32768) {
        res = -32768;
    } else if (tmp_res > 32767) {
        res = 32767;
    } else {
        res = (int) tmp_res;
    }

    DPRINT("readNTCSeat2: val & uref & resNTC: ");
    DPRINT(val);
    DPRINT(" ");
    DPRINT(uref);
    DPRINT(" ");
    DPRINT(res);
    DPRINT("\n");


    return( res );
}

/* Variables for Heating
 */ 
bool stHeat = true;
bool stCoolDown = false;
uint32_t timer = 0UL;
/* Stop heating after 1200000ms = 1200s = 20min
 * Start heating again after 10000ms = 10s */ 
const uint32_t timer_heat = 1200000UL;
const uint32_t timer_cool = 10000UL;
const int relaisPin = 7;
const int maxTemp = 55;

ISR(TIMER0_COMPA_vect){    //This is the interrupt request
  timer++;
}

const int SerialSpeed = 9600;

void setup() {
    Serial.begin(SerialSpeed);

    /* LCD start backlight */
    lcd.init();
    lcd.backlight();
    delay(250);
    lcd.noBacklight();
    delay(1000);
    lcd.backlight();
    delay(1000);

    /* Start timer, interval 1ms */
    /* CTC - Clear Timer on CompareCTC - Clear Timer on Compare*/
    TCCR0A = 1<<WGM01;
    OCR0A = 0xF9;
    TIMSK0|=(1<<OCIE0A);   //Set the interrupt request
    sei(); //Enable interrupt
 
    TCCR0B|=(1<<CS01);    //Set the prescale 1/64 clock
    TCCR0B|=(1<<CS00);


    pinMode(analogPinSeat1, INPUT);
    pinMode(analogPinSeat2, INPUT);
    pinMode(AnalogPinRef, INPUT);
    pinMode(relaisPin, OUTPUT);
    digitalWrite(relaisPin, HIGH);
}

uint8_t skipClear = 0;
void updateDisplay(int tempRear, int tempSeat, bool stRear, bool stSeat) {
    OVERWRITE(tempRear, 10)
    OVERWRITE(tempSeat, 20)
    OVERWRITE(stRear, true)
    OVERWRITE(stSeat, false)
    
    if(skipClear == 0U) {
        lcd.clear();
    }
    skipClear = (skipClear + 1U) % 5;

    lcd.setCursor(0,0);
    lcd.print("Ruckenlehne");
    lcd.setCursor(0,1);
    lcd.print("Temp: ");
    lcd.print(tempRear);
    lcd.print("C -");
    lcd.setCursor(14,1);
    lcd.print(stRear ? "Heizen" : "Warten");

    lcd.setCursor(0,2);
    lcd.print("Sitzflache");
    lcd.setCursor(0,3);
    lcd.print("Temp: ");
    lcd.print(tempSeat);
    lcd.print("C -");
    lcd.setCursor(14,3);
    lcd.print(stSeat ? "Heizen" : "Warten");

    return;
}

long memCoolDown = 0UL;

void loop() {
    float uref = readRefVoltage();

    int ntc_seat1 = readNTCSeat1(uref);
    int ntc_seat2 = readNTCSeat2(uref);
    int temp_seat1 = convertTemp(ntc_seat1);
    int temp_seat2 = convertTemp(ntc_seat2);
    DPRINT("Main loop: ntc_seat1 / temp_seat1: ");
    DPRINT(ntc_seat1);
    DPRINT(" / ");
    DPRINT(temp_seat1);
    DPRINT("\n");
    updateDisplay(temp_seat1, temp_seat2, stHeat, stHeat);


    if( stHeat && timer > timer_heat ) {
        /* Stop heating until reset */ 
        stHeat = false;
        timer = 0UL;
        digitalWrite(relaisPin, stHeat);
    }

    if( stHeat && (temp_seat1 > maxTemp || temp_seat2 > maxTemp) ) {
        memCoolDown = timer;
        stHeat = false;
        stCoolDown = true;
        digitalWrite(relaisPin, stHeat);
    }
    
    if ( !stHeat && stCoolDown && timer > (memCoolDown + timer_cool) ) {
        /* Start heating again */ 
        stHeat = true;
        memCoolDown = 0UL;
        digitalWrite(relaisPin, stHeat);
    }
    delay(1000);
}

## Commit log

2026-02-22 README: Wooden plate
2026-03-22 First working version
    [schematics.kicad_pcb, schematics.kicad_sch]
